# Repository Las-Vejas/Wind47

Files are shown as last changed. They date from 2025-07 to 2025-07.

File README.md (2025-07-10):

# Wind47

This is a 60% Ortho linear keyboard, made with Gateron low profile red switches, sk6812mini leds, 2 rotary encoders and a RP2040 Pro Micro.
The keyboard uses a sandwich case, and will probably use QMK for software, but i will do that when i assemble the keyboard.

I made this project to try out making a keyboard, and i wanted to try out an ortholinear keyboard.




I couldn't find a 2U keycap anywhere and im just so done :sob:

## PCB



## Schematic



## Case

- Bottom
case bottom

- Middle plate


- Top frame


## BOM

| **Quantity** | **Value** | **Price** | **Link** |
| --- | --- | --- | --- |
| 5 | Pcb | $12.50 | N/A |
| 47 | Gateron Low Profile Red Switches | $19.10 | [Link](https://www.aliexpress.com/item/1005006870413847.html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) |
| 47 | Hot Swap Socket | $7.21 | [Link](https://www.aliexpress.com/item/1005006042596309.html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) |
| 47 | SK6812MINI LED | $3.73 | [Link](https://www.aliexpress.com/item/1005007863635868.html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,scm-url:1007.40050.354490.0,pvid:7b6b9416-d88f-40ac-8c6e-72acea23db31,tpp_buckets:668%232846%238113%231998&isseo=y&pdp_ext_f=%7B%22order%22%3A%2258%22%2C%22eval%22%3A%221%22%2C%22sceneId%22%3A%2230050%22%7D&pdp_npi=4%40dis%21USD%213.75%210.99%21%21%213.75%210.99%21%40211b441e17518085375406647e0c46%2112000042594617264%21rec%21LT%216401819456%21ABX&utparam-url=scene%3ApcDetailTopMoreOtherSeller%7Cquery_from%3A) |
| 47 | Diode | $1.27 | [Link](https://www.aliexpress.com/item/1005001994794541.html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) |
| 4 | Heatsets | $4.01 | [Link](https://www.aliexpress.com/item/1005006838108683.html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) |
| 4 | M2.5 x 16 mm screws | $2.92 | [Link](https://www.aliexpress.com/item/32981974171.html) |
| 2 | RP2040 pro micro | $7.08 | [Link](https://www.aliexpress.com/item/1005006130019224.html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) |
| 2 | Rotary Encoder Switch | $4.02 | [Link](https://www.aliexpress.com/item/32976046900.html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) |
| 1 | Keycaps | $14.31 | [Link](https://www.aliexpress.com/item/1005004870848679.html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) |
| 1 | 2U Stabiliser | $2.61 | [Link](https://www.aliexpress.com/item/32864782721.html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) |
| 1 | Hex wrench | $2.47 | [Link](https://www.aliexpress.com/item/1005005430749401.html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) |
| | **Total:** | $88.68 | |
| | Aliexpress Shipping | $7.45 | N/A |

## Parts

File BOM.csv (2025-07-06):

Quantity | Value | Price | Link
1 | 2U Stabiliser | $2.61 | https://www.aliexpress.com/item/32864782721.html?mp=1
1 | Keycaps | $12.07 | https://www.aliexpress.com/item/1005004870848679.html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
1 | Hex wrench | $2.47 | https://www.aliexpress.com/item/1005005430749401.html?mp=1
2 | Rotary Encoder Switch | $4.02 | https://www.aliexpress.com/item/32976046900.html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
2 | RP2040 pro micro | $7.08 | RP2040 Pro Micro
4 | M2.5 x 16 mm screws | $2.92 | https://www.aliexpress.com/item/32981974171.html
4 | Heatsets | $4.01 | https://www.aliexpress.com/item/1005006838108683.html?mp=1
5 | Pcb | $12.50
47 | Diode | $1.27 | https://www.aliexpress.com/item/1005001994794541.html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
47 | SK6812MINI LED | $3.75 | https://www.aliexpress.com/item/1005007863635868.html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
47 | Gateron Low Profile Red Switches | $13.14 | https://www.aliexpress.com/item/1005006870413847.html?mp=1
47 | Hot Swap Socket | $7.21 | https://www.aliexpress.com/item/1005006042596309.html?mp=1
 | Aliexpress Shipping | $7.45

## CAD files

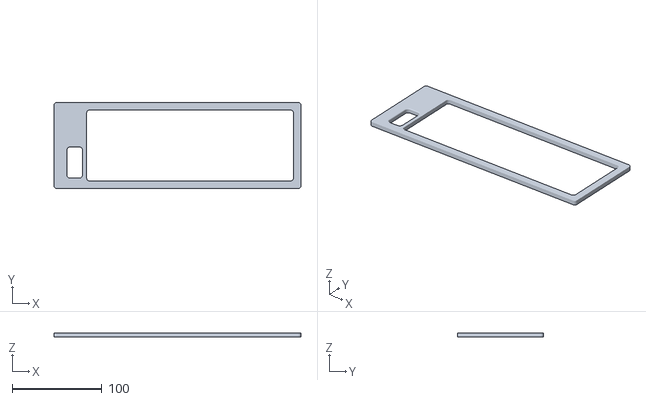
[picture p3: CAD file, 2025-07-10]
production/Wind47-pcb (top).stl
275.4 x 96.0 x 5.00

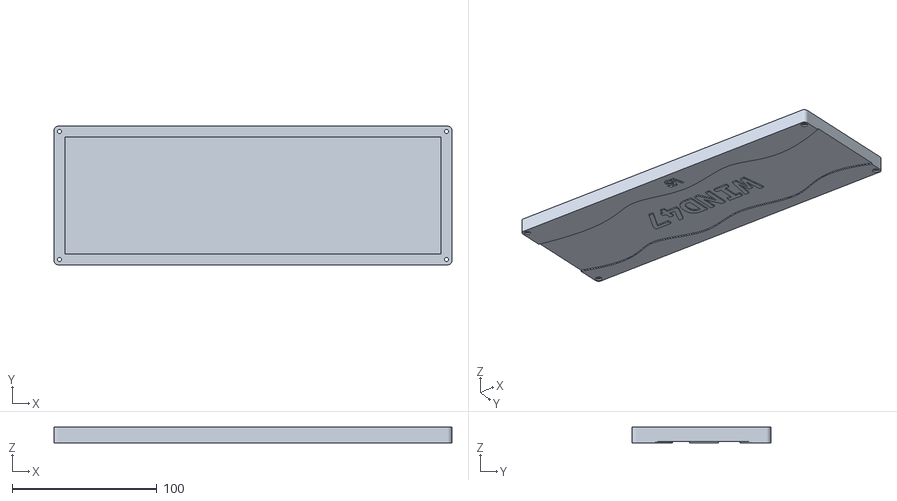
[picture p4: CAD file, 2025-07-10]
production/Wind47-pcb (bottom).stl
275.4 x 96.0 x 11.0

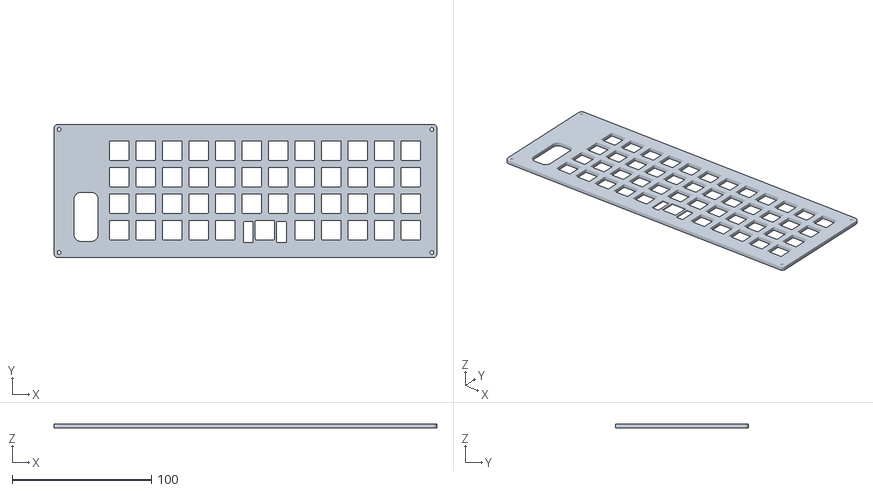
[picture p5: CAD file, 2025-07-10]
production/Wind47-pcb (middle).stl
275.4 x 96.0 x 3.00

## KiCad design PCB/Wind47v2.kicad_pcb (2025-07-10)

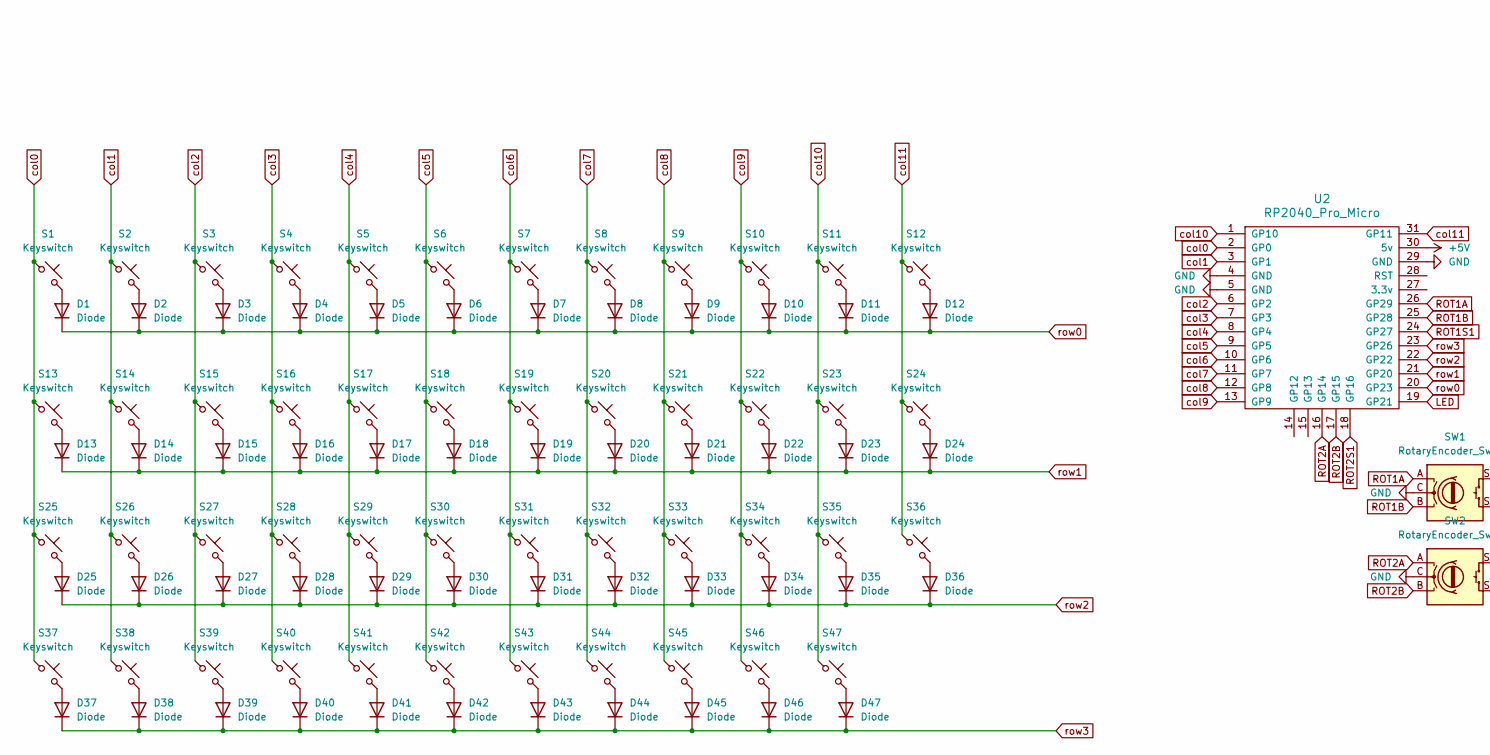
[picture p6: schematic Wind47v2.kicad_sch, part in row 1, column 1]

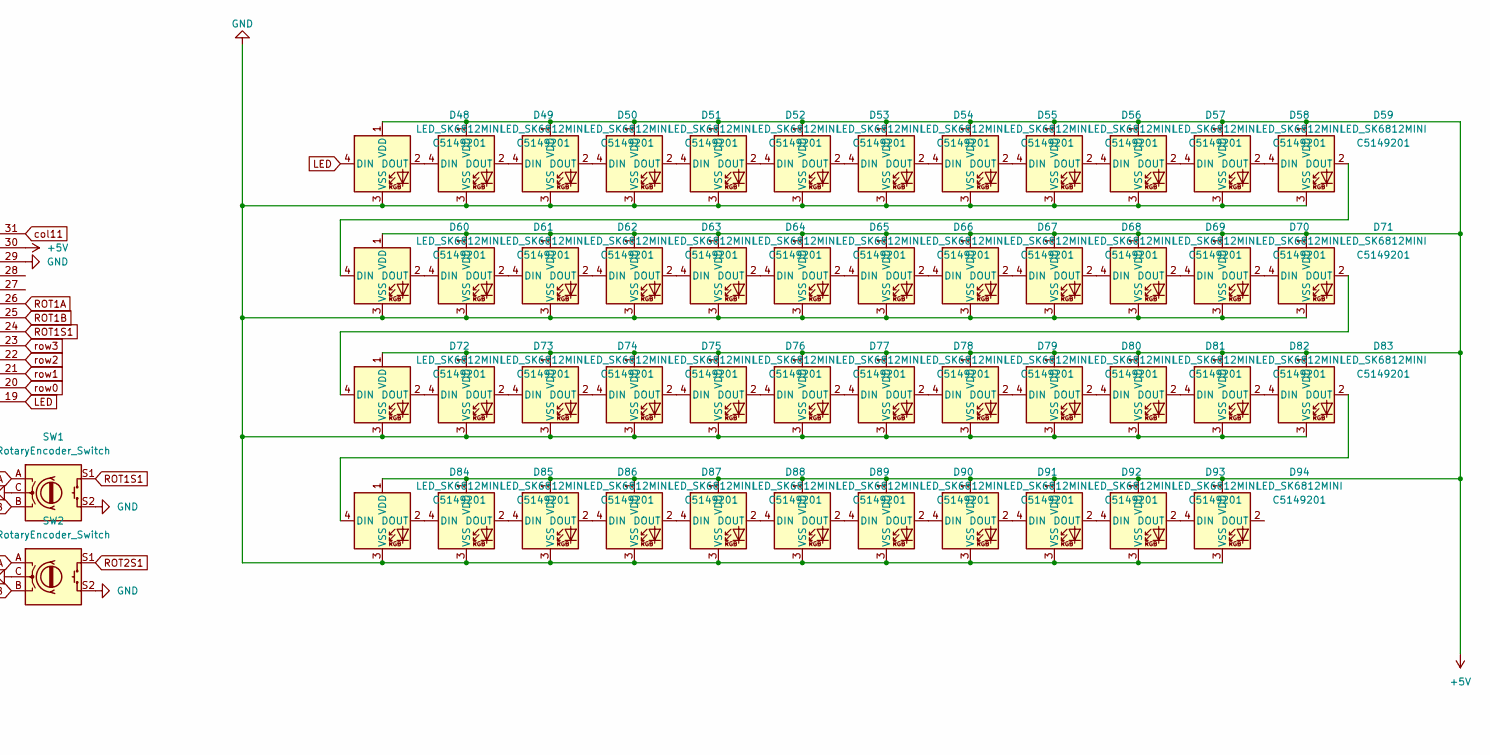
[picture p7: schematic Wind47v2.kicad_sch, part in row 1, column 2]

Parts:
D1, D2, D3, D4, D5, D6, D7, D8, D9, D10, D11, D12, D13, D14, D15, D16, D17, D18, D19, D20, D21, D22, D23, D24, D25, D26, D27, D28, D29, D30, D31, D32, D33, D34, D35, D36, D37, D38, D39, D40, D41, D42, D43, D44, D45, D46, D47: Diode; D_SOD-123
D48, D49, D50, D51, D52, D53, D54, D55, D56, D57, D58, D59, D60, D61, D62, D63, D64, D65, D66, D67, D68, D69, D70, D71, D72, D73, D74, D75, D76, D77, D78, D79, D80, D81, D82, D83, D84, D85, D86, D87, D88, D89, D90, D91, D92, D93, D94: LED_SK6812MINI; LCSC C5149201
S1, S2, S3, S4, S5, S6, S7, S8, S9, S10, S11, S12, S13, S14, S15, S16, S17, S18, S19, S20, S21, S22, S23, S24, S25, S26, S27, S28, S29, S30, S31, S32, S33, S34, S35, S36, S37, S38, S39, S40, S41, S42, S43, S44, S45, S46, S47: Keyswitch; SW_Gateron_LowProfile_HotSwap_PTH
SW1, SW2: RotaryEncoder_Switch; RotaryEncoder_Alps_EC11E-Switch_Vertical_H20mm_CircularMoun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
U2: RP2040_Pro_Micro

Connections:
+5V: D48.1 (VDD), D49.1 (VDD), D50.1 (VDD), D51.1 (VDD), D52.1 (VDD), D53.1 (VDD), D54.1 (VDD), D55.1 (VDD), D56.1 (VDD), D57.1 (VDD), D58.1 (VDD), D59.1 (VDD), D60.1 (VDD), D61.1 (VDD), D62.1 (VDD), D63.1 (VDD), D64.1 (VDD), D65.1 (VDD), D66.1 (VDD), D67.1 (VDD), D68.1 (VDD), D69.1 (VDD), D70.1 (VDD), D71.1 (VDD), D72.1 (VDD), D73.1 (VDD), D74.1 (VDD), D75.1 (VDD), D76.1 (VDD), D77.1 (VDD), D78.1 (VDD), D79.1 (VDD), D80.1 (VDD), D81.1 (VDD), D82.1 (VDD), D83.1 (VDD), D84.1 (VDD), D85.1 (VDD), D86.1 (VDD), D87.1 (VDD), D88.1 (VDD), D89.1 (VDD), D90.1 (VDD), D91.1 (VDD), D92.1 (VDD), D93.1 (VDD), D94.1 (VDD), U2.30 (5v)
GND: D48.3 (VSS), D49.3 (VSS), D50.3 (VSS), D51.3 (VSS), D52.3 (VSS), D53.3 (VSS), D54.3 (VSS), D55.3 (VSS), D56.3 (VSS), D57.3 (VSS), D58.3 (VSS), D59.3 (VSS), D60.3 (VSS), D61.3 (VSS), D62.3 (VSS), D63.3 (VSS), D64.3 (VSS), D65.3 (VSS), D66.3 (VSS), D67.3 (VSS), D68.3 (VSS), D69.3 (VSS), D70.3 (VSS), D71.3 (VSS), D72.3 (VSS), D73.3 (VSS), D74.3 (VSS), D75.3 (VSS), D76.3 (VSS), D77.3 (VSS), D78.3 (VSS), D79.3 (VSS), D80.3 (VSS), D81.3 (VSS), D82.3 (VSS), D83.3 (VSS), D84.3 (VSS), D85.3 (VSS), D86.3 (VSS), D87.3 (VSS), D88.3 (VSS), D89.3 (VSS), D90.3 (VSS), D91.3 (VSS), D92.3 (VSS), D93.3 (VSS), D94.3 (VSS), SW1.C, SW1.S2, SW2.C, SW2.S2, U2.4 (GND), U2.5 (GND), U2.29 (GND)
LED: D48.4 (DIN), U2.19 (GP21)
unnamed: D1.2 (A), S1.2
unnamed: D2.2 (A), S2.2
unnamed: D3.2 (A), S3.2
unnamed: D4.2 (A), S4.2
unnamed: D5.2 (A), S5.2
unnamed: D6.2 (A), S6.2
unnamed: D7.2 (A), S7.2
unnamed: D8.2 (A), S8.2
unnamed: D9.2 (A), S9.2
unnamed: D10.2 (A), S10.2
unnamed: D11.2 (A), S11.2
unnamed: D12.2 (A), S12.2
unnamed: D13.2 (A), S13.2
unnamed: D14.2 (A), S14.2
unnamed: D15.2 (A), S15.2
unnamed: D16.2 (A), S16.2
unnamed: D17.2 (A), S17.2
unnamed: D18.2 (A), S18.2
unnamed: D19.2 (A), S19.2
unnamed: D20.2 (A), S20.2
unnamed: D21.2 (A), S21.2
unnamed: D22.2 (A), S22.2
unnamed: D23.2 (A), S23.2
unnamed: D24.2 (A), S24.2
unnamed: D25.2 (A), S25.2
unnamed: D26.2 (A), S26.2
unnamed: D27.2 (A), S27.2
unnamed: D28.2 (A), S28.2
unnamed: D29.2 (A), S29.2
unnamed: D30.2 (A), S30.2
unnamed: D31.2 (A), S31.2
unnamed: D32.2 (A), S32.2
unnamed: D33.2 (A), S33.2
unnamed: D34.2 (A), S34.2
unnamed: D35.2 (A), S35.2
unnamed: D36.2 (A), S36.2
unnamed: D37.2 (A), S37.2
unnamed: D38.2 (A), S38.2
unnamed: D39.2 (A), S39.2
unnamed: D40.2 (A), S40.2
unnamed: D41.2 (A), S41.2
unnamed: D42.2 (A), S42.2
unnamed: D43.2 (A), S43.2
unnamed: D44.2 (A), S44.2
unnamed: D45.2 (A), S45.2
unnamed: D46.2 (A), S46.2
unnamed: D47.2 (A), S47.2
unnamed: D48.2 (DOUT), D49.4 (DIN)
unnamed: D49.2 (DOUT), D50.4 (DIN)
unnamed: D50.2 (DOUT), D51.4 (DIN)
unnamed: D51.2 (DOUT), D52.4 (DIN)
unnamed: D52.2 (DOUT), D53.4 (DIN)
unnamed: D53.2 (DOUT), D54.4 (DIN)
unnamed: D54.2 (DOUT), D55.4 (DIN)
unnamed: D55.2 (DOUT), D56.4 (DIN)
unnamed: D56.2 (DOUT), D57.4 (DIN)
unnamed: D57.2 (DOUT), D58.4 (DIN)
unnamed: D58.2 (DOUT), D59.4 (DIN)
unnamed: D59.2 (DOUT), D60.4 (DIN)
unnamed: D60.2 (DOUT), D61.4 (DIN)
unnamed: D61.2 (DOUT), D62.4 (DIN)
unnamed: D62.2 (DOUT), D63.4 (DIN)
unnamed: D63.2 (DOUT), D64.4 (DIN)
unnamed: D64.2 (DOUT), D65.4 (DIN)
unnamed: D65.2 (DOUT), D66.4 (DIN)
unnamed: D66.2 (DOUT), D67.4 (DIN)
unnamed: D67.2 (DOUT), D68.4 (DIN)
unnamed: D68.2 (DOUT), D69.4 (DIN)
unnamed: D69.2 (DOUT), D70.4 (DIN)
unnamed: D70.2 (DOUT), D71.4 (DIN)
unnamed: D71.2 (DOUT), D72.4 (DIN)
unnamed: D72.2 (DOUT), D73.4 (DIN)
unnamed: D73.2 (DOUT), D74.4 (DIN)
unnamed: D74.2 (DOUT), D75.4 (DIN)
unnamed: D75.2 (DOUT), D76.4 (DIN)
unnamed: D76.2 (DOUT), D77.4 (DIN)
unnamed: D77.2 (DOUT), D78.4 (DIN)
unnamed: D78.2 (DOUT), D79.4 (DIN)
unnamed: D79.2 (DOUT), D80.4 (DIN)
unnamed: D80.2 (DOUT), D81.4 (DIN)
unnamed: D81.2 (DOUT), D82.4 (DIN)
unnamed: D82.2 (DOUT), D83.4 (DIN)
unnamed: D83.2 (DOUT), D84.4 (DIN)
unnamed: D84.2 (DOUT), D85.4 (DIN)
unnamed: D85.2 (DOUT), D86.4 (DIN)
unnamed: D86.2 (DOUT), D87.4 (DIN)
unnamed: D87.2 (DOUT), D88.4 (DIN)
unnamed: D88.2 (DOUT), D89.4 (DIN)
unnamed: D89.2 (DOUT), D90.4 (DIN)
unnamed: D90.2 (DOUT), D91.4 (DIN)
unnamed: D91.2 (DOUT), D92.4 (DIN)
unnamed: D92.2 (DOUT), D93.4 (DIN)
unnamed: D93.2 (DOUT), D94.4 (DIN)
ROT1A: SW1.A, U2.26 (GP29)
ROT1B: SW1.B, U2.25 (GP28)
ROT1S1: SW1.S1, U2.24 (GP27)
ROT2A: SW2.A, U2.16 (GP14)
ROT2B: SW2.B, U2.17 (GP15)
ROT2S1: SW2.S1, U2.18 (GP16)
col0: S1.1, S13.1, S25.1, S37.1, U2.2 (GP0)
col1: S2.1, S14.1, S26.1, S38.1, U2.3 (GP1)
col2: S3.1, S15.1, S27.1, S39.1, U2.6 (GP2)
col3: S4.1, S16.1, S28.1, S40.1, U2.7 (GP3)
col4: S5.1, S17.1, S29.1, S41.1, U2.8 (GP4)
col5: S6.1, S18.1, S30.1, S42.1, U2.9 (GP5)
col6: S7.1, S19.1, S31.1, S43.1, U2.10 (GP6)
col7: S8.1, S20.1, S32.1, S44.1, U2.11 (GP7)
col8: S9.1, S21.1, S33.1, S45.1, U2.12 (GP8)
col9: S10.1, S22.1, S34.1, S46.1, U2.13 (GP9)
col10: S11.1, S23.1, S35.1, S47.1, U2.1 (GP10)
col11: S12.1, S24.1, S36.1, U2.31 (GP11)
row0: D1.1 (K), D2.1 (K), D3.1 (K), D4.1 (K), D5.1 (K), D6.1 (K), D7.1 (K), D8.1 (K), D9.1 (K), D10.1 (K), D11.1 (K), D12.1 (K), U2.20 (GP23)
row1: D13.1 (K), D14.1 (K), D15.1 (K), D16.1 (K), D17.1 (K), D18.1 (K), D19.1 (K), D20.1 (K), D21.1 (K), D22.1 (K), D23.1 (K), D24.1 (K), U2.21 (GP20)
row2: D25.1 (K), D26.1 (K), D27.1 (K), D28.1 (K), D29.1 (K), D30.1 (K), D31.1 (K), D32.1 (K), D33.1 (K), D34.1 (K), D35.1 (K), D36.1 (K), U2.22 (GP22)
row3: D37.1 (K), D38.1 (K), D39.1 (K), D40.1 (K), D41.1 (K), D42.1 (K), D43.1 (K), D44.1 (K), D45.1 (K), D46.1 (K), D47.1 (K), U2.23 (GP26)

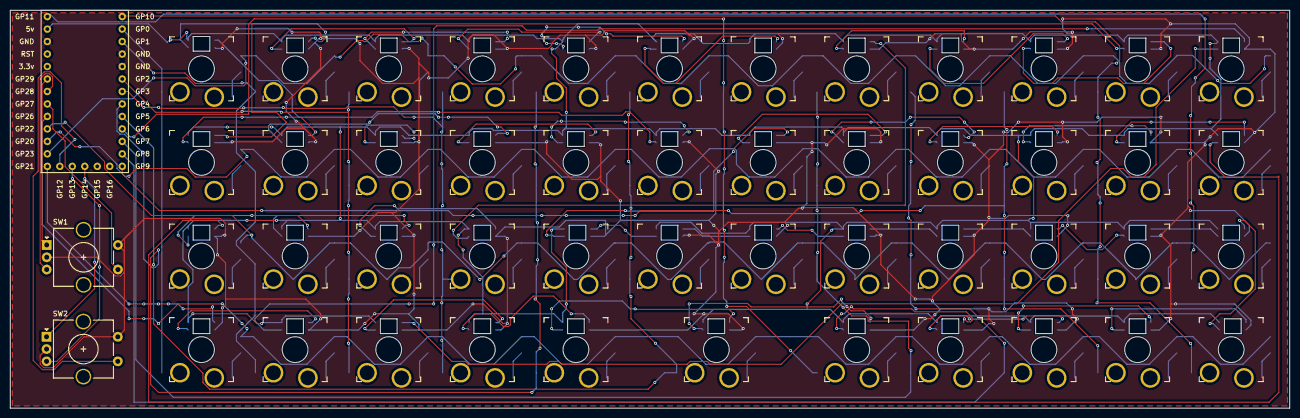
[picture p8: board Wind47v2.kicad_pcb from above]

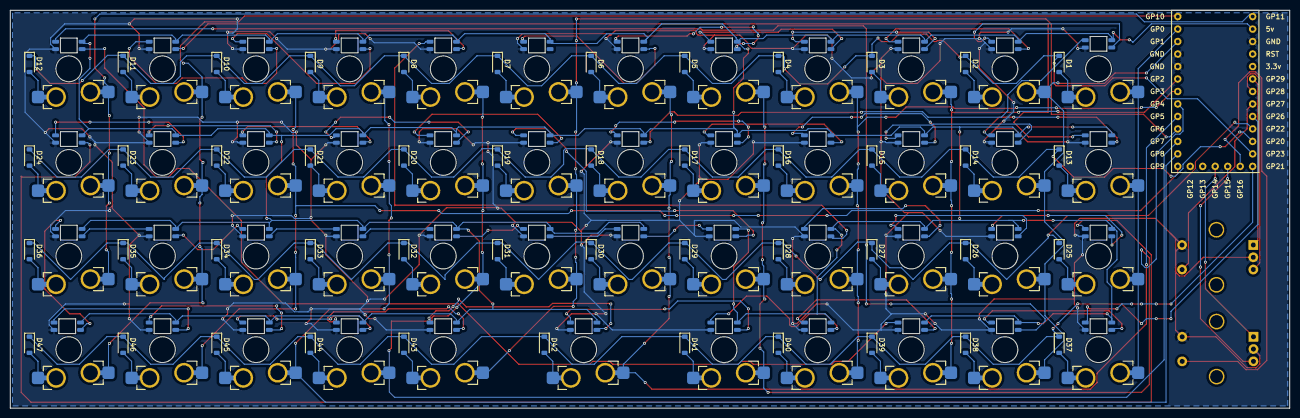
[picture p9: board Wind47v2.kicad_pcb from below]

Board: 2 copper layers, 260.4 x 81.0 mm, 144 parts (95 on the bottom side), 118 nets.

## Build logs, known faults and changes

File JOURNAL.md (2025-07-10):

---
title: “Wind47"
author: “Vejas Sereicikas"
description: “An ortholinear, 60%, low profile keyboard."
created_at: "2024-07-02"
---

## Journal

(This was written after my project, so this will only be the end of the development.)

# July 7th 2025

I added 2 rotary encoders and linked them up. (I changed the 3d models accordingly later.)

Probably fixed up the case.

(3-ish hours)

# July 8th 2025

I resubmitted my project and got a tip from Logan (@Logan Peterson on Hackclub Slack) that I should make my case design more intricate. 

I decided to make the name of my keyboard more visible, so I added a big ‘WIND47’ on the back, drew a few waves on top and on the bottom of the text and extruded the middle inwards. Also added holes for the rotary encoders.

Case bottom Wind47

Also had a massive fight with Shapr3d, Fusion, KiCad and the lack of 3d models (and the lack of storage :sob:).

(6-ish hours)

## July 10th 2025

09:08 - I realized I didn’t put a usb-c port opening on my 3d file :see-no-evil:. I will try to make it in Shapr3d.

I noticed that the microcontroller was going through the floor so I lowered the floor down from 3mm to 1.5mm. I added the port opening, and rounded the edges.

SCR-20250710-irpq

(~30 mins)

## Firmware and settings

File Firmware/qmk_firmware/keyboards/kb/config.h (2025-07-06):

#ifndef CONFIG_H
#define CONFIG_H

#include "config_common.h"

/* USB Device descriptor parameter */
#define VENDOR_ID       0xFEED
#define PRODUCT_ID      0x6060
#define DEVICE_VER      0x0001
#define MANUFACTURER    qmkbuilder
#define PRODUCT         keyboard
#define DESCRIPTION     Keyboard

/* key matrix size */
#define MATRIX_ROWS 4
#define MATRIX_COLS 12

/* key matrix pins */
#define MATRIX_ROW_PINS { B0, B1, B2, B3 }
#define MATRIX_COL_PINS { B4, B5, B6, B7, C0, C1, C2, C3, C4, C5, C6, C7 }
#define UNUSED_PINS

/* COL2ROW or ROW2COL */
#define DIODE_DIRECTION COL2ROW

/* number of backlight levels */

#ifdef BACKLIGHT_PIN
#define BACKLIGHT_LEVELS 3
#endif

/* Set 0 if debouncing isn't needed */
#define DEBOUNCING_DELAY 5

/* Mechanical locking support. Use KC_LCAP, KC_LNUM or KC_LSCR instead in keymap */
#define LOCKING_SUPPORT_ENABLE

/* Locking resynchronize hack */
#define LOCKING_RESYNC_ENABLE

/* key combination for command */
#define IS_COMMAND() ( \
    keyboard_report->mods == (MOD_BIT(KC_LSHIFT) | MOD_BIT(KC_RSHIFT)) \
)

/* prevent stuck modifiers */
#define PREVENT_STUCK_MODIFIERS


#ifdef RGB_DI_PIN
#define RGBLIGHT_ANIMATIONS
#define RGBLED_NUM 0
#define RGBLIGHT_HUE_STEP 8
#define RGBLIGHT_SAT_STEP 8
#define RGBLIGHT_VAL_STEP 8
#endif

#endif

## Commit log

2025-07-03 Started and almost finished the schem
    [SolarKey.kicad_pcb, SolarKey.kicad_sch]
2025-07-04 Initial commit
    Add initial project files and setup.
    [SolarKey.kicad_pcb, SolarKey.kicad_sch]
2025-07-06 a lot of work
    [SolarKey.kicad_pcb, SolarKey.kicad_sch, Wind47 Bottom printable.stl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]
2025-07-06 update gerbers
2025-07-06 update kicad files
    [SolarKey.kicad_pcb, SolarKey.kicad_sch]
2025-07-06 rename kicad files
    [Wind47.kicad_pcb, Wind47.kicad_sch]
2025-07-06 more work idk
    [BOM.csv]
2025-07-07 Rename Wind47-pcb (~recovered).zip to CAD/Wind47-pcb (~recovered).zip
2025-07-10 Update PCB net assignments and production files
    Renamed and reordered several net assignments in Wind47v2.kicad_pcb to remove unused nets and improve clarity. Updated production STL and ZIP files, removed outdated backups, and added new 3D and PCB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
    [Wind47 Middle printable.stl, Wind47 Top printable.stl, Wind47-pcb (bottom).stl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]
2025-07-10 Update bottom case image
2025-07-10 Update BOM
